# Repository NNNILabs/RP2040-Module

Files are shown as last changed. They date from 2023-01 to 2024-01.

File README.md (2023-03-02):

# RP2040 Module
## Introduction
A small-footprint RP2040 breakout board, with additional features like extended memory and a fast optically-isolated interface. 
## Project Motivation
Two projects of mine, a [breakout board](https://github.com/NNNILabs/AD4630-Wideband-Digital-LNA) investigating the AD4630 and a [modular power supply](https://github.com/diminDDL/TripleChannelPSU), both needed a compact RP2040 breakout board. Since they needed some shared features, I decided to make one board to use with both (and possibly more) projects.
## Usage
[under construction]
## List of Files
- Hardware: KiCAD PCB files, 3D models
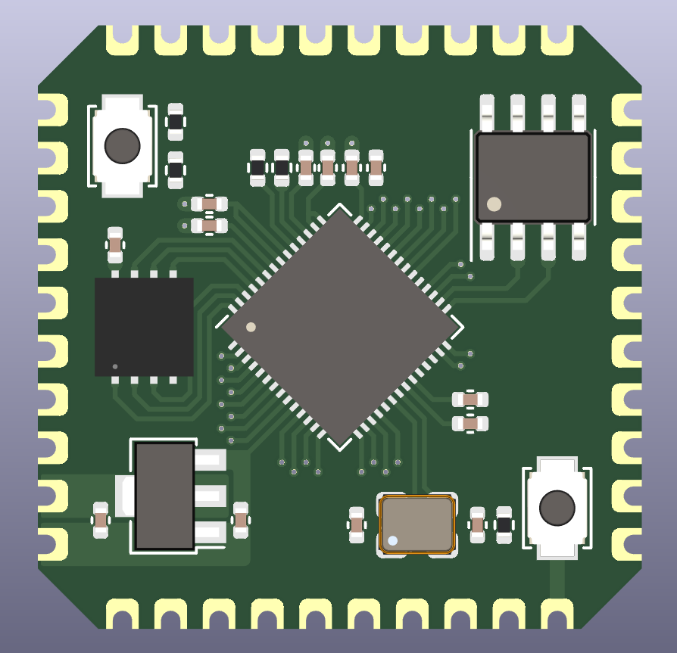
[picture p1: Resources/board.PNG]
PCB Front

- Resources: Pinout diagram
## Application Examples
[under construction]
## Notes
- Projects like the [RP2040 Stamp](https://shop.pimoroni.com/products/rp2040-stamp?variant=39567567028307) and the [RP2040 ISP Stamp](https://www.osborneee.com/rp2040-isp-stamp/) exist, but they lack some of the features I need and modifying the files was very difficult because of sketchy layout. I decided I could do better in the latter aspect. 
## Links
[under construction]

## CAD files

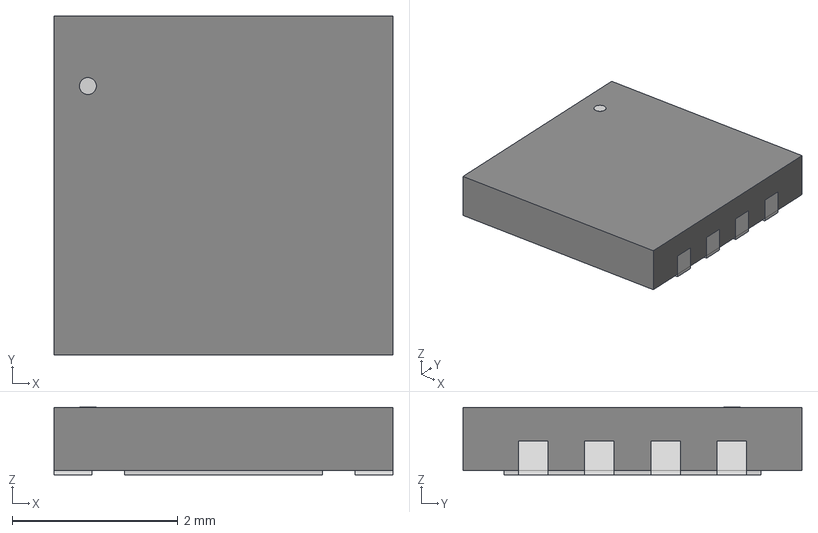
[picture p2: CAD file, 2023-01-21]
Hardware/25Q64/25Q64.step
4.09 x 4.09 x 0.815 mm

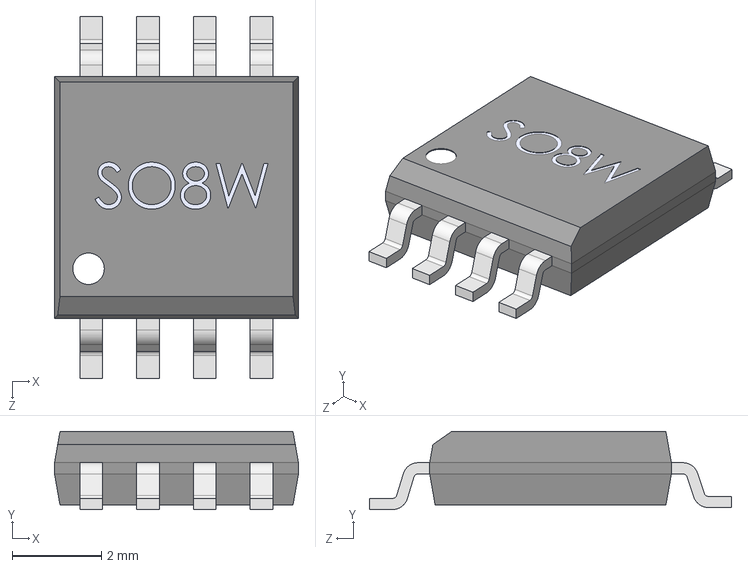
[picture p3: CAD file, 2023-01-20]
Hardware/SOIC-8 Wide.step
5.46 x 1.75 x 8.10 mm

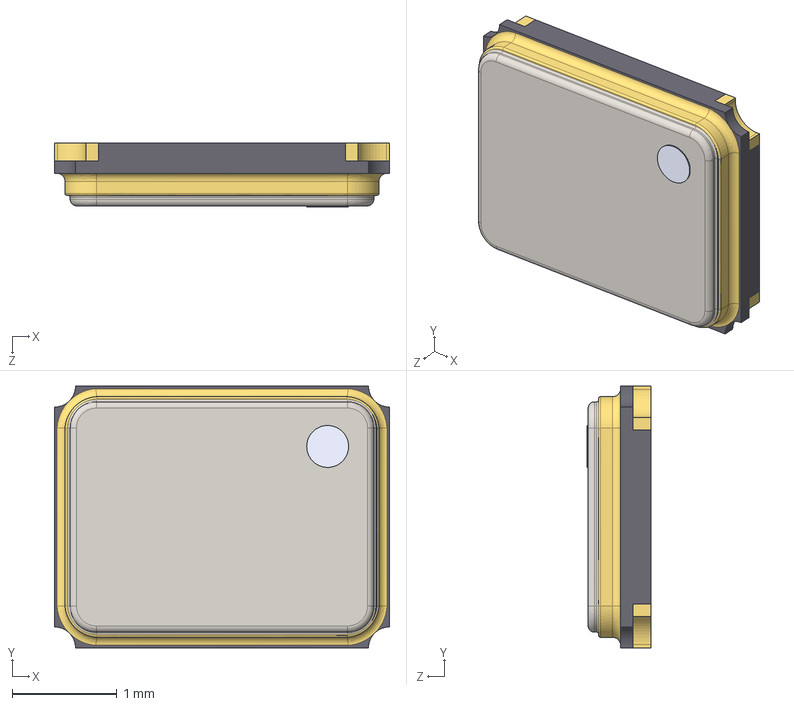
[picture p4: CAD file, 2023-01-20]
Hardware/3225 Crystal.step
3.20 x 2.50 x 0.61 mm

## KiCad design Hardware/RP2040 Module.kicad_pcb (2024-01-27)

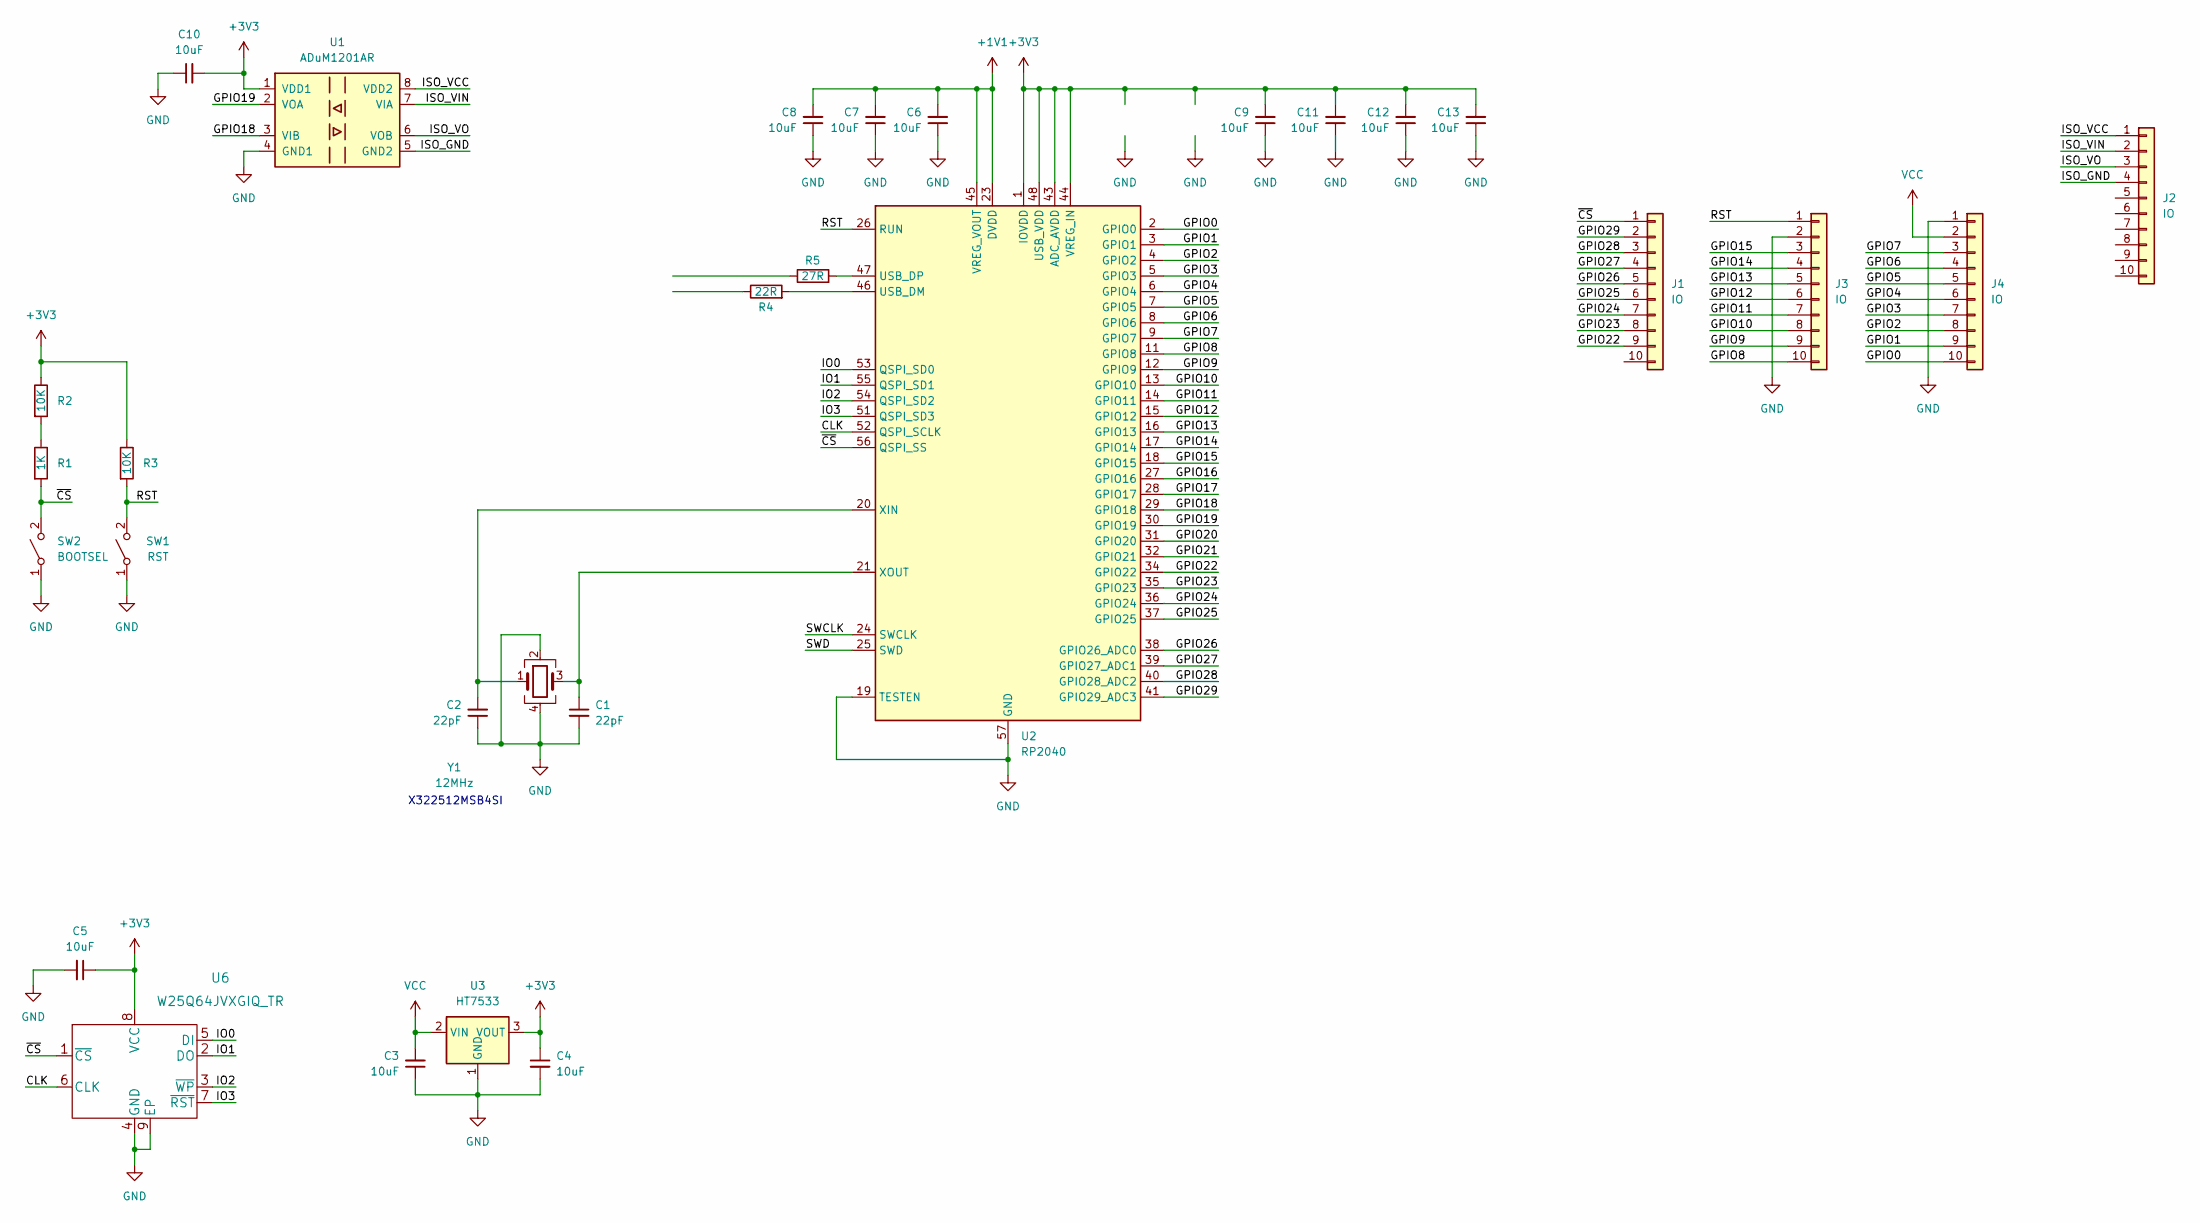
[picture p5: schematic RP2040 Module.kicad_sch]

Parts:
C1, C2: 22pF; C_0402_1005Metric
C3, C4, C5, C6, C7, C8, C9, C10, C11, C12, C13: 10uF; C_0402_1005Metric
J1, J2, J3, J4: IO; PinHeader_1x10_P2.00mm_Vertical
R1: 1K; R_0402_1005Metric
R2, R3: 10K; R_0402_1005Metric
R4: 22R; R_0402_1005Metric
R5: 27R; R_0402_1005Metric
SW1: RST; SW_SPST_B3U-1000P
SW2: BOOTSEL; SW_SPST_B3U-1000P
U1: ADuM1201AR; SOIC-8_3.9x4.9mm_P1.27mm
U2: RP2040; QFN-56-1EP_7x7mm_P0.4mm_EP3.2x3.2mm
U3: HT7533; SOT-89-3
U6: W25Q64JVXGIQ_TR; W25Q64JVXGIQ TR
Y1: 12MHz; Oscillator_SMD_Abracon_ASE-4Pin_3.2x2.5mm

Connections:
+1V1: C6.2, C7.2, C8.2, U2.23 (DVDD), U2.45 (VREG_VOUT), U2.50 (DVDD)
+3V3: C4.1, C5.1, C9.2, C10.2, C11.2, C12.2, C13.2, R2.1, R3.1, U1.1 (VDD1), U2.1 (IOVDD), U2.10 (IOVDD), U2.22 (IOVDD), U2.33 (IOVDD), U2.42 (IOVDD), U2.43 (ADC_AVDD), U2.44 (VREG_IN), U2.48 (USB_VDD), U2.49 (IOVDD), U3.3 (VOUT), U6.8 (VCC)
/CLK: U2.52 (QSPI_SCLK), U6.6 (CLK)
/GPIO0: J4.10, U2.2 (GPIO0)
/GPIO1: J4.9, U2.3 (GPIO1)
/GPIO2: J4.8, U2.4 (GPIO2)
/GPIO3: J4.7, U2.5 (GPIO3)
/GPIO4: J4.6, U2.6 (GPIO4)
/GPIO5: J4.5, U2.7 (GPIO5)
/GPIO6: J4.4, U2.8 (GPIO6)
/GPIO7: J4.3, U2.9 (GPIO7)
/GPIO8: J3.10, U2.11 (GPIO8)
/GPIO9: J3.9, U2.12 (GPIO9)
/GPIO10: J3.8, U2.13 (GPIO10)
/GPIO11: J3.7, U2.14 (GPIO11)
/GPIO12: J3.6, U2.15 (GPIO12)
/GPIO13: J3.5, U2.16 (GPIO13)
/GPIO14: J3.4, U2.17 (GPIO14)
/GPIO15: J3.3, U2.18 (GPIO15)
/GPIO16: U2.27 (GPIO16)
/GPIO17: U2.28 (GPIO17)
/GPIO18: U1.3 (VIB), U2.29 (GPIO18)
/GPIO19: U1.2 (VOA), U2.30 (GPIO19)
/GPIO20: U2.31 (GPIO20)
/GPIO21: U2.32 (GPIO21)
/GPIO22: J1.9, U2.34 (GPIO22)
/GPIO23: J1.8, U2.35 (GPIO23)
/GPIO24: J1.7, U2.36 (GPIO24)
/GPIO25: J1.6, U2.37 (GPIO25)
/GPIO26: J1.5, U2.38 (GPIO26_ADC0)
/GPIO27: J1.4, U2.39 (GPIO27_ADC1)
/GPIO28: J1.3, U2.40 (GPIO28_ADC2)
/GPIO29: J1.2, U2.41 (GPIO29_ADC3)
/IO0: U2.53 (QSPI_SD0), U6.5 (DI)
/IO1: U2.55 (QSPI_SD1), U6.2 (DO)
/IO2: U2.54 (QSPI_SD2), U6.3 (~WP)
/IO3: U2.51 (QSPI_SD3), U6.7 (~RST)
/ISO_GND: J2.4, U1.5 (GND2)
/ISO_VCC: J2.1, U1.8 (VDD2)
/ISO_VIN: J2.2, U1.7 (VIA)
/ISO_VO: J2.3, U1.6 (VOB)
/RST: J3.1, R3.2, SW1.2 (B), U2.26 (RUN)
/SWCLK: U2.24 (SWCLK)
/SWD: U2.25 (SWD)
/~CS: J1.1, R1.2, SW2.2 (B), U2.56 (QSPI_SS), U6.1 (~CS)
GND: C1.2, C2.1, C3.1, C4.2, C5.2, C6.1, C7.1, C8.1, C9.1, C10.1, C11.1, C12.1, C13.1, J3.2, J4.1, SW1.1 (A), SW2.1 (A), U1.4 (GND1), U2.19 (TESTEN), U2.57 (GND), U3.1 (GND), U6.4 (GND), U6.9 (EP), Y1.2, Y1.4
unnamed: R1.1, R2.2
unnamed: R4.2, U2.46 (USB_DM)
unnamed: R5.2, U2.47 (USB_DP)
unnamed: C2.2, U2.20 (XIN), Y1.1
unnamed: C1.1, U2.21 (XOUT), Y1.3
VCC: C3.2, J4.2, U3.2 (VIN)

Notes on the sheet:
X322512MSB4SI

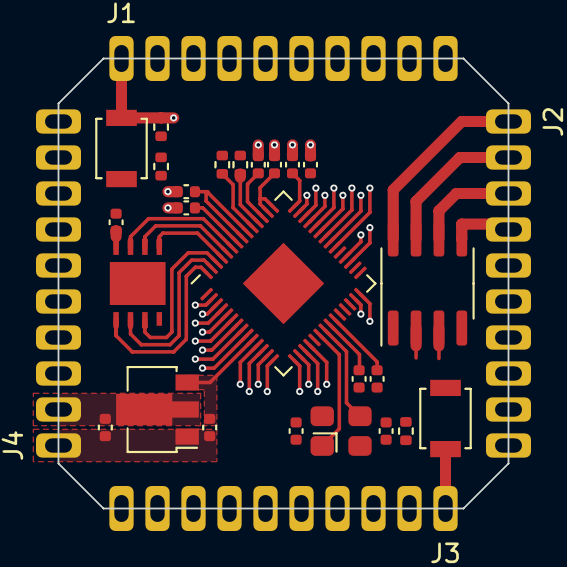
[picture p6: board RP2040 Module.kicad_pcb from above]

Board: 4 copper layers, 25.0 x 25.0 mm, 29 parts (0 on the bottom side), 46 nets.

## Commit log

2023-01-20 updated files
    [RP2040 Module.kicad_pcb, RP2040 Module.kicad_sch]
2024-01-27 sync update
    [RP2040 Module.kicad_pcb]
